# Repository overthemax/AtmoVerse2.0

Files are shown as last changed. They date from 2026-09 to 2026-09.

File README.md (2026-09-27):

<div align="center">

# AtmoVerse

**An e-ink weather station for your home: time, weather and a literary quote, on electronic paper.**

ESP32 · 5.83″ e-ink display · battery powered · self-updating from GitHub · Italian / English

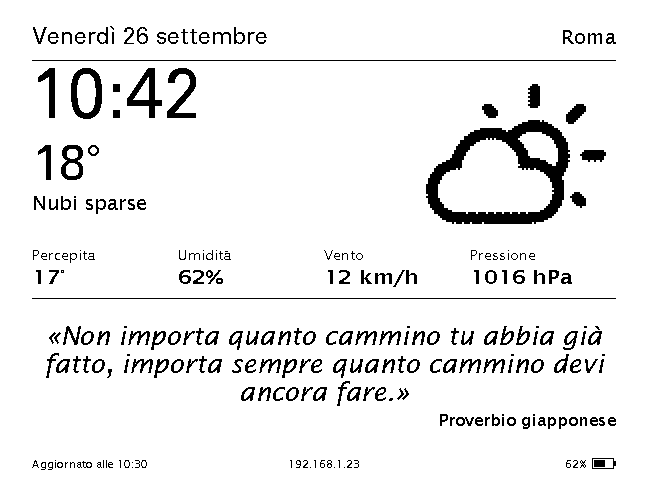
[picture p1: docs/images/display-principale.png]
AtmoVerse main screen


</div>

---

## What it does

- **Weather at a glance.** Temperature, feels-like, humidity, wind and pressure from OpenWeatherMap, with icons drawn for e-ink.
- **A literary clock.** At many minutes of the day it shows a quote from a book that mentions that exact time. Otherwise it picks a quote that suits the weather and the time of day, or one you scheduled for a given day and hour. The font adapts to the length, so quotes are never cut.
- **Setup from your phone.** On first start the display shows a QR code: scan it, the phone joins AtmoVerse's network and the setup page opens by itself.
- **Updates itself.** Firmware, web pages and icons come from GitHub releases, each file verified with SHA-256, with automatic rollback if a new firmware fails to start.
- **Lasts on battery.** On battery the WiFi is switched on only when needed and the board sleeps between minute refreshes. Touching a case screw wakes the web page for 10 minutes.
- **Two languages.** Display and web pages in Italian or English, chosen in the settings.
- **Keeps working offline.** A DS3231 real-time clock keeps the time without internet; if the home network drops, AtmoVerse reconnects by itself.

<table>
  <tr>
    <td align="center" width="50%">
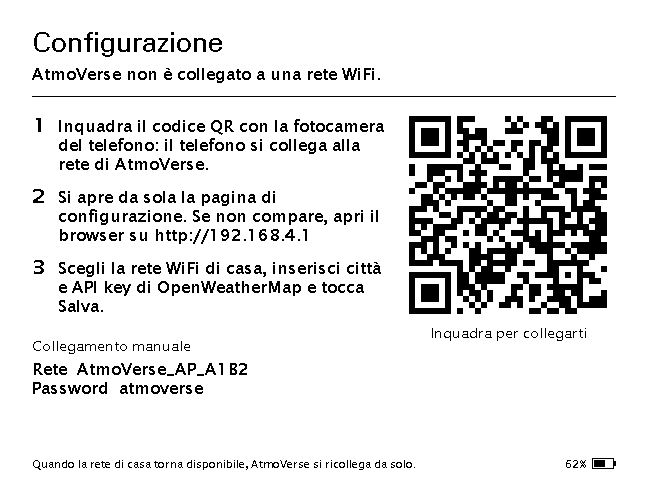
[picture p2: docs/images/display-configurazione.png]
Setup screen with QR code
      <br>
      <sub><b>First setup</b> · scan the QR code and follow three steps</sub>
    </td>
    <td align="center" width="50%">
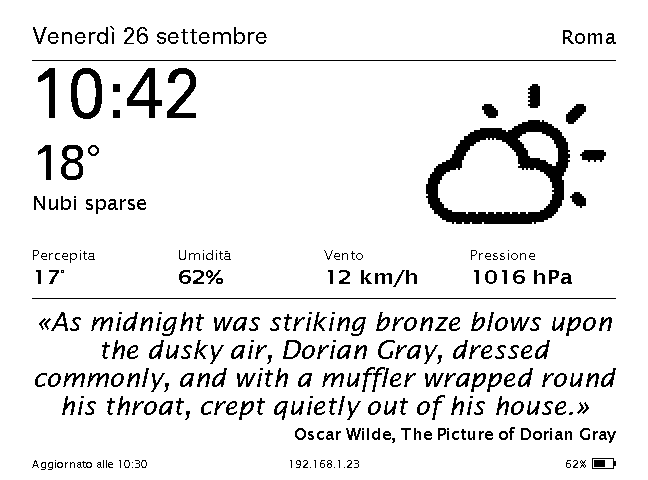
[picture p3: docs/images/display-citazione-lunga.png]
Long quote with adaptive font
      <br>
      <sub><b>Adaptive font</b> · long quotes stay whole</sub>
    </td>
  </tr>
  <tr>
    <td align="center" width="50%">
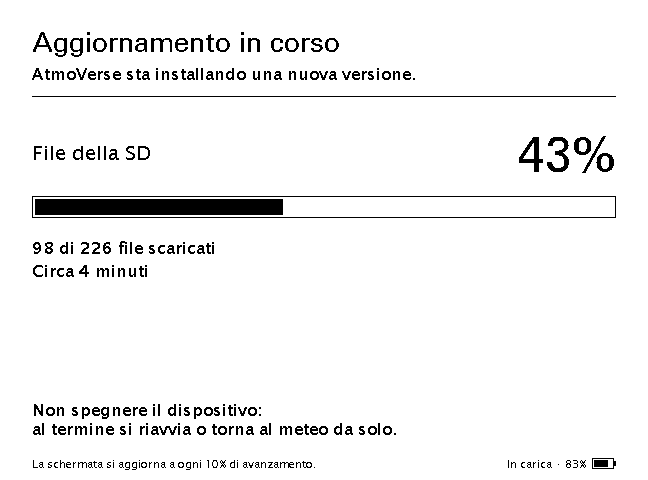
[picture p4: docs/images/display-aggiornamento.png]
Update in progress screen
      <br>
      <sub><b>Updates</b> · progress, files and remaining time</sub>
    </td>
    <td align="center" width="50%">
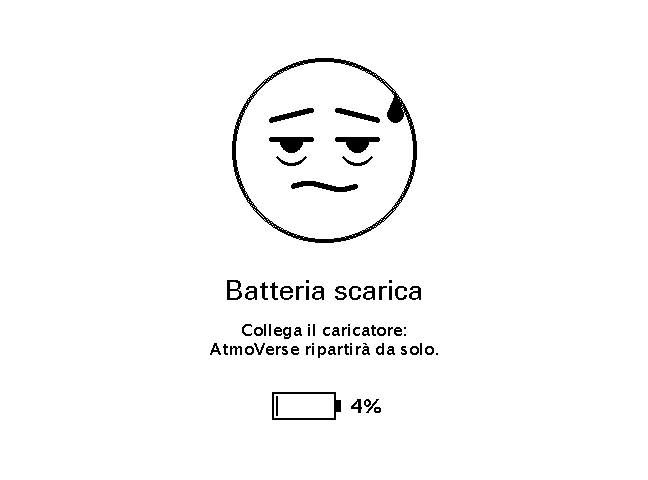
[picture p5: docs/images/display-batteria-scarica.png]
Empty battery screen
      <br>
      <sub><b>Battery empty</b> · the board sleeps until it is charged</sub>
    </td>
  </tr>
</table>

<sub>Images are rendered from the code with the display's real fonts (<code>tools/preview_display.py</code>), with sample data, in Italian.</sub>

---

## Hardware

| Part | Model | Connection |
|---|---|---|
| Board | WEMOS LOLIN32 (ESP32, 4 MB flash) | — |
| Display | 5.83″ e-ink 648×480, GDEW0583T8 (bare panel + driver board) | SPI (VSPI): BUSY 4 · RST 16 · DC 17 · CS 5 · SCK 18 · MOSI 23 |
| SD card | microSD FAT32 module | SPI (HSPI): CS 14 · SCK 27 · MOSI 26 · MISO 25 |
| Clock | DS3231 | I²C (Wire1): SDA 13 · SCL 15 |
| Battery | LiPo pack, 2 × 3500 mAh in parallel (66 × 43 × 13 mm) | measured by INA219 on I²C (Wire): SDA 32 · SCL 33, address 0x41 |
| Touch button | a case screw wired to GPIO2 (touch T2) | ring terminal under the screw |

### Case

A two-part desk case with soft rounded lines and a cylindrical stand that tilts the display by 15°. The front frame holds the panel; the back cover carries the stand and cradles for the battery and modules, and closes with four M3 screws into heat-set inserts.

<table>
  <tr>
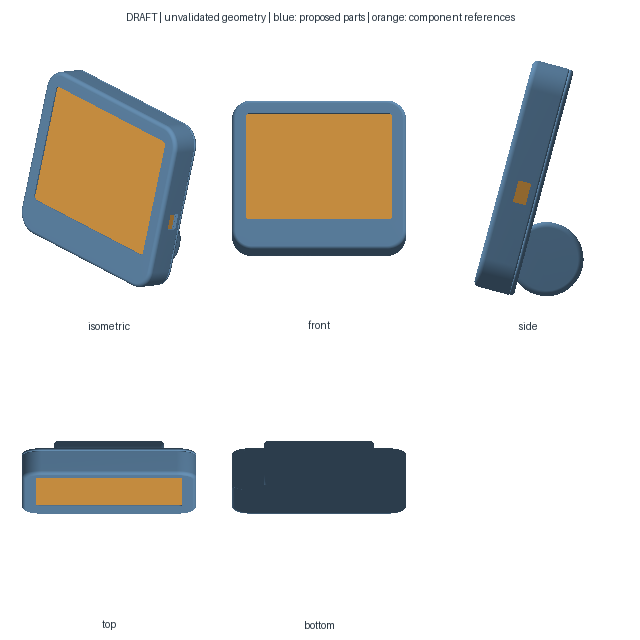
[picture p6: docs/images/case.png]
Case on the desk
    <td align="center" width="50%"><br><sub><b>On the desk</b></sub></td>
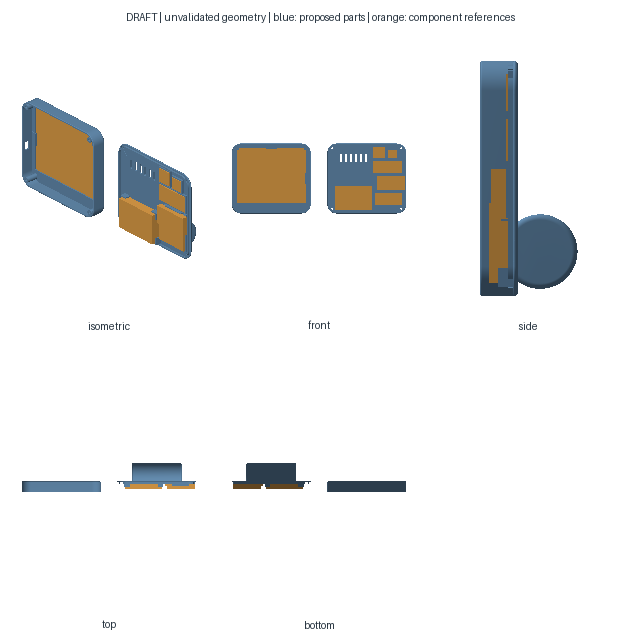
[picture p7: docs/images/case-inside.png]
Case exploded view
    <td align="center" width="50%"><br><sub><b>Inside</b> · frame and back cover</sub></td>
  </tr>
</table>

- Print-ready files: [`cad/stampa/`](cad/stampa) (STL and STEP). Print the frame face down; print the back cover standing on its bottom edge, with supports under the cylinder.
- Parametric source: [`cad/model_build.py`](cad/model_build.py) (build123d).
- Hardware: 4 × M3 screws, 4 × M3 heat-set inserts (Ø 4 mm), one M3 ring terminal for the touch screw.
- Module sizes are measured: LOLIN32 50.5 × 26.3 mm, e-paper driver 48.5 × 22.7 mm (its thickness, 6 mm, is estimated).

---

## Installation

### 1. First firmware upload (once)

One USB upload is enough: from then on AtmoVerse updates itself.

Requirements: [Arduino CLI](https://arduino.github.io/arduino-cli/) or Arduino IDE with **esp32 core 3.3.8** and these libraries:

| Library | Version |
|---|---|
| GxEPD2 | 1.6.9 |
| Adafruit GFX Library · Adafruit BusIO | 1.12.6 · 1.17.4 |
| U8g2_for_Adafruit_GFX | 1.8.0 |
| ArduinoJson | 7.4.3 |
| RTClib | 2.1.4 |
| Adafruit INA219 | 1.2.3 |

Connect the board and run, from PowerShell in the project folder:

```powershell
.\upload_lolin32_bigapp.ps1 -Port COM4
```

The script uses `partitions.csv`, which splits the flash into two 1.9 MB app slots needed by the automatic updates.

### 2. SD card

Any FAT32 microSD, even empty: web pages and icons are downloaded from GitHub the first time AtmoVerse goes online.

### 3. First setup

1. Switch AtmoVerse on: with no network configured it shows the QR code screen.
2. Scan the QR code with your phone camera. The phone joins `AtmoVerse_AP_xxxx` and the setup page opens (otherwise open `http://192.168.4.1`).
3. Enter your home WiFi, your city and an [OpenWeatherMap API key](https://openweathermap.org/api) (free), then tap **Save**.

AtmoVerse restarts, connects, downloads what is missing and shows the weather. The interface language can be changed later in **Settings → Language**.

---

## Quotes

For every display refresh the quote is chosen in this order:

1. **Scheduled**, if one is active: with a start time and duration, days of the week, or a date (every year or once).
2. **Literary clock**: a quote that mentions the current time, from `/clock/00.txt … 23.txt` on the SD card (optional).
3. **Weather**: a quote from the `quotes.json` section for the current weather (`rain`, `light_rain`, `thunderstorm`, `storm`, `clear_sky`, `few_clouds`, `scattered_clouds`, `cloudy`, `fog`, `snow`, `wind`), preferring quotes tagged for the time of day (`period`: `morning`, `afternoon`, `evening`, `day`, `night`) and the season (`season`: `winter`, `spring`, `summer`, `autumn`).

Everything is edited from the web editor (`/quotes-editor.html`), which has two tabs:

- **Weather and scheduled** — the quotes in `quotes.json`.
- **Literary clock** — one hour at a time, with the covered minutes for each hour and a warning on quotes too long for the display (checked by the board with the real fonts).

Example of a scheduled quote in `quotes.json`:

```json
"scheduled": [
  { "text": "Good morning! Every morning is a blank page.", "author": "Anonymous",
    "at": "07:00", "duration": 90, "days": "mon,tue,wed,thu,fri" }
]
```

`date` (`"12-25"` every year, `"2026-12-25"` once) can replace or accompany `at`. Files written before version 2.1.17 use Italian names (`programmate`, `ora`, `durata`, `giorni`, `data`, `pioggia`…): the device still reads them, and the editor converts the file to the English names on the first save, after downloading a backup copy. The `/orari` folder is renamed to `/clock` automatically at start-up.

The `/clock` files can also be generated from a CSV `HH:MM|phrase|text|work|author`. They live on the SD card only and are never part of the repository or of the updates:

```bash
python tools/make_clock_quotes.py quotes.csv E:/
```

---

## Power

| Power source | Behaviour |
|---|---|
| **Charger connected** | Everything always on: WiFi, web page, display refresh every minute. |
| **Battery** | WiFi off except for short windows: weather and time every 30 minutes, update check every 6 hours. Between minute refreshes the ESP32 is in light sleep. |
| **Battery, after a touch** | Touching the screw wakes the board: WiFi and web page stay on for 10 minutes, extended by every request. A WiFi icon next to the city shows when the WiFi is on. |

Plugging or unplugging the charger is detected within 2 seconds. The touch threshold is recalibrated at every change of power source, and false touches are ignored.

Battery levels: a warning in the footer at 15%, and at 5% the display shows an empty-battery screen and the board sleeps, checking every 30 minutes until it is charged. A new firmware is not installed below 25% unless the charger is connected.

---

## Automatic updates

At start-up and every 6 hours AtmoVerse checks the latest release and downloads only what changed.

- **Chain of trust.** The release information comes from `api.github.com` with a verified certificate, including the SHA-256 of `manifest.json`. The manifest is accepted only if its hash matches, and it carries the SHA-256 of the firmware and of every SD file. GitHub serves release files from a CDN whose Let's Encrypt "Root YR" chain the ESP32 certificate bundle cannot verify, so those downloads are encrypted but checked by hash instead.
- **SD files** (`sd_files/`): prepared in `/upd` and applied all together, even after an interruption. The release the SD card matches is remembered, so the periodic check skips re-hashing every file (a manual check from the web page always does the full check).
- **Firmware**: written to the second app slot, 3 attempts. If the new version does not survive its first 60 seconds, the bootloader goes back to the previous one and the faulty version is never downloaded again.
- **Personal files** (settings, `quotes.json`, `/clock`): never overwritten.
- If the SD card is full, the display explains how much space is needed.

### Publishing a new version

```bash
git tag v2.1.11
git push origin v2.1.11
```

The GitHub Action [`release.yml`](.github/workflows/release.yml) builds the firmware, generates the manifest with [`tools/make_manifest.py`](tools/make_manifest.py) and publishes the release. Devices install it at their next check, or immediately with **Settings → Check for updates**.

---

## Web interface

Reachable at the IP address shown at the bottom of the display (during setup: `http://192.168.4.1`). Designed for smartphones first. The pages are written in Italian and translated to English by [`sd_files/www/i18n.js`](sd_files/www/i18n.js) when English is selected.

<table>
  <tr>
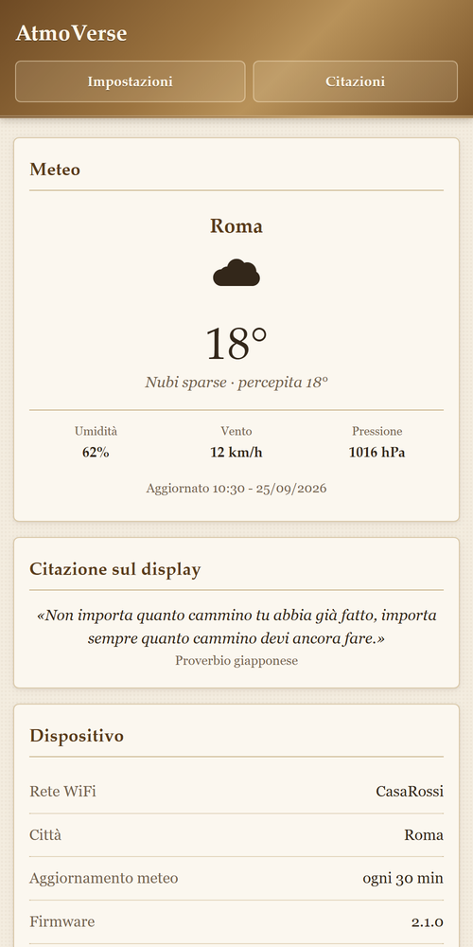
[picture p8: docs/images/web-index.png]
Home with weather and quote
    <td align="center" width="33%"><br><sub><b>Home</b></sub></td>
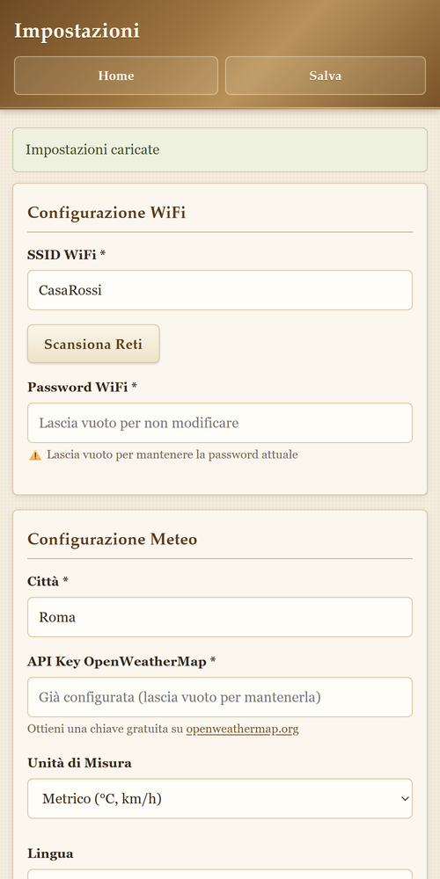
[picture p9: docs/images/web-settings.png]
Settings
    <td align="center" width="33%"><br><sub><b>Settings</b></sub></td>
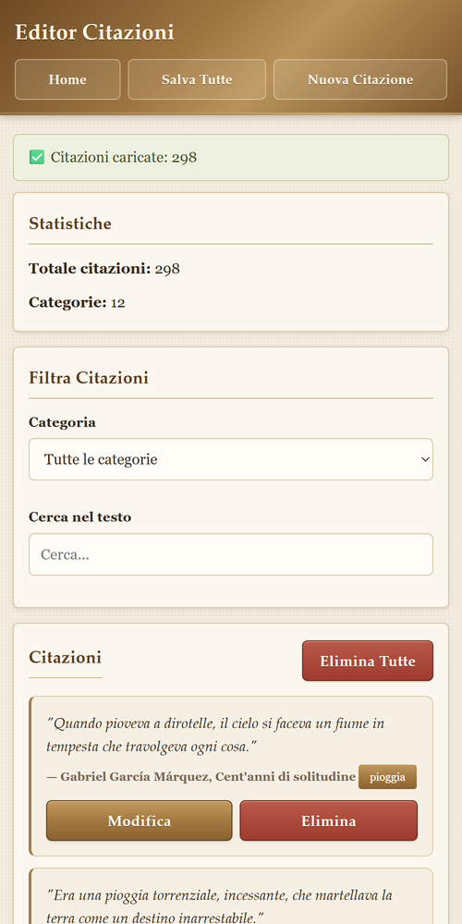
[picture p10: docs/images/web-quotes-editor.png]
Quote editor
    <td align="center" width="33%"><br><sub><b>Quotes</b></sub></td>
  </tr>
</table>

| API | Description |
|---|---|
| `GET /api/weather` | Current weather |
| `GET/POST /api/settings` | Read or save the settings. The API key is never returned; an empty password or API key keeps the stored one |
| `GET /api/wifi/scan` | Visible WiFi networks |
| `GET /quotes.json` · `POST /api/quotes/raw` | Read or save the weather and scheduled quotes (the whole file, written via a temporary file) |
| `GET /api/quote/current` | Quote shown on the display |
| `GET /api/clock` | Literary clock summary: quotes and covered minutes per hour |
| `GET /api/clock?h=8` · `?h=8&fit=1` | One hour of the literary clock, or which of its quotes fit the display |
| `POST /api/clock?h=8` | Save one hour (plain text, max 64 KB, written via a temporary file) |
| `GET /api/battery` | Voltage, current, percentage, charging |
| `GET /api/health` | Uptime, free memory, IP address, WiFi signal, SD card (used by the diagnostics page) |
| `POST /api/update/check` | Check for updates now |
| `POST /api/restart` | Restart the device |

> The web interface has no password: anyone on your home network can change the settings. Use AtmoVerse only on networks you trust.

---

## Architecture

The ESP32's two cores are used like this:

| Core | Runs |
|---|---|
| **Core 1** · main loop | Web server and captive portal, weather, updates, quotes, battery, RTC, SD card, power management |
| **Core 0** · display task | Drawing and refreshing the e-ink panel (about 4.5 s), at low priority next to the WiFi stack |

The loop prepares a snapshot of the screen (data, quote, icon already read from the SD card) and hands it to the display task, then goes straight back to the network: the web page keeps answering during a refresh. The display task never touches the SD card or the network; the only shared data is the pending screen, protected by a mutex. The display and the SD card use separate SPI buses, so they really work in parallel.

The CPU runs at 80 MHz, downloads included: raising it to 240 MHz during downloads made the HTTPS connections fail.

## Project layout

| File | Contents |
|---|---|
| `AtmoVerse_2.0.ino` | Start-up, main loop, network and periodic tasks |
| `DisplayTask.cpp` | Display task on core 0 |
| `Screens.cpp` | Display screens: layout, typography, adaptive quote, WiFi icon |
| `Display.cpp` | Building the screens in the loop (data, quote, icon) |
| `EcoPower.cpp` | Battery power saving, WiFi windows, light sleep, touch button |
| `Language.cpp` | Interface language |
| `Updater.cpp` | Automatic updates from GitHub with rollback |
| `WeatherUtils.cpp` | Weather from OpenWeatherMap (HTTPS) |
| `QuotesManager.cpp` | Quote selection |
| `QRCodeHelper.cpp` | QR codes with the ESP-IDF `esp_qrcode` component |
| `WebServer.cpp` · `WebMinimal.cpp` | Web interface, API and the minimal setup page built into the firmware |
| `NetworkUtils.cpp` | WiFi, access point mode, time zone |
| `BatteryManager.cpp` · `RTCManager.cpp` | Battery (INA219) and clock (DS3231) |
| `sd_files/` | SD card contents distributed with the updates |
| `cad/` | Case source and print files |
| `tools/` | Display previews, manifest, literary clock files, icon download and conversion |
| `tests/` | Hardware test sketches for the display and the SD card |

---

## Credits

- Weather icons: [Weather Icons](https://erikflowers.github.io/weather-icons/) by Erik Flowers ([SIL OFL 1.1](LICENSES/OFL-1.1.txt)), converted to bitmaps for e-ink.
- Fonts: FreeUniversal (SIL OFL 1.1) and Lucida Sans (© Bigelow & Holmes, X11 font license) through [U8g2](https://github.com/olikraus/u8g2).
- Weather data provided by [OpenWeather](https://openweathermap.org).
- Libraries: GxEPD2, Adafruit GFX, Adafruit BusIO, Adafruit INA219, RTClib, ArduinoJson, U8g2_for_Adafruit_GFX, Arduino core for ESP32 / ESP-IDF.
- Case modelled with [build123d](https://github.com/gumyr/build123d) and [Amagine3D](https://github.com/amagine-ai/Amagine3D).
- Design inspired by literary clocks such as [Author Clock](https://www.authorandco.com/).

Full list with versions and licenses: [THIRD_PARTY_NOTICES.md](THIRD_PARTY_NOTICES.md).

## License

The source code of AtmoVerse is released under the [MIT license](LICENSE) © overthemax.

The firmware binaries in the releases include GxEPD2, licensed under the GNU GPL v3, so each binary as a whole is distributed under the GPL v3; its complete source is this repository at the release tag. Third-party libraries, fonts and icons keep their own licenses, listed in [THIRD_PARTY_NOTICES.md](THIRD_PARTY_NOTICES.md).

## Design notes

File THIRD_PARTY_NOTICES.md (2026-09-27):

# Third-party notices

AtmoVerse's own source code is released under the [MIT license](LICENSE).
It uses the third-party software and assets listed below, each under its own license.

## Firmware binaries

The firmware published in the GitHub releases (`firmware.bin`) is built with the
libraries below. Because it links **GxEPD2**, which is licensed under the
**GNU GPL v3**, the firmware binary as a whole is distributed under the terms of
the GPL v3. The complete corresponding source code is this repository at the
release tag, plus the library versions listed here.

## Libraries (linked into the firmware, not included in this repository)

| Library | Version | License | Copyright |
|---|---|---|---|
| [GxEPD2](https://github.com/ZinggJM/GxEPD2) | 1.6.9 | GPL-3.0 | Jean-Marc Zingg |
| [Adafruit GFX Library](https://github.com/adafruit/Adafruit-GFX-Library) | 1.12.6 | BSD-2-Clause | Adafruit Industries |
| [Adafruit BusIO](https://github.com/adafruit/Adafruit_BusIO) | 1.17.4 | MIT | Adafruit Industries |
| [Adafruit INA219](https://github.com/adafruit/Adafruit_INA219) | 1.2.3 | BSD | Adafruit Industries |
| [RTClib](https://github.com/adafruit/RTClib) | 2.1.4 | MIT | Adafruit Industries, JeeLabs |
| [ArduinoJson](https://github.com/bblanchon/ArduinoJson) | 7.4.3 | MIT | Benoît Blanchon |
| [U8g2_for_Adafruit_GFX](https://github.com/olikraus/U8g2_for_Adafruit_GFX) | 1.8.0 | BSD-2-Clause | olikraus |
| [Arduino core for ESP32](https://github.com/espressif/arduino-esp32) | 3.3.8 | LGPL-2.1 | Espressif Systems |
| [ESP-IDF](https://github.com/espressif/esp-idf) (incl. mbedTLS, esp_http_client, esp_qrcode) | bundled with the core | Apache-2.0 (esp_qrcode uses Project Nayuki's QR Code generator, MIT) | Espressif Systems and contributors |

## Fonts (compiled into the firmware from U8g2)

| Font | Used for | License |
|---|---|---|
| FreeUniversal (`u8g2_font_fur*`) | time and temperature | SIL Open Font License 1.1 — FreeUniversal © Stephen Wilson 2009, based on Sil Sophia © SIL International 1994–2008 |
| Lucida Sans (`u8g2_font_lu*`) | text, labels, quotes | X11 bitmap fonts by Bigelow & Holmes: © Bigelow & Holmes 1985, 1986, redistributed under the X Window System font license. Lucida is a registered trademark of Bigelow & Holmes |

## Icons (included in this repository)

`sd_files/icons/` are converted from
[Weather Icons](https://erikflowers.github.io/weather-icons/) by Erik Flowers,
licensed under the [SIL Open Font License 1.1](LICENSES/OFL-1.1.txt).

## Data and services

- Weather data: [OpenWeather](https://openweathermap.org), used through the
  user's own API key and under OpenWeather's terms of service (data licensed
  CC BY-SA 4.0). Attribution: *Weather data provided by OpenWeather*.
- Updates: GitHub Releases and the GitHub REST API.

## Quotes

Quotes are short excerpts attributed to their authors and works. The literary
clock files (`/clock`) are not part of this repository or of the updates: they
stay on the user's own SD card.

## Tools (not distributed with the firmware)

- The case is modelled with [build123d](https://github.com/gumyr/build123d)
  (Apache-2.0) and the [Amagine3D](https://github.com/amagine-ai/Amagine3D)
  skill (Apache-2.0).
- The case design is original; its soft, rounded look was inspired by
  literary clocks such as [Author Clock](https://www.authorandco.com/). No
  part of their design files, logos or trademarks is used.

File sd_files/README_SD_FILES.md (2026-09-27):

# SD card files

The firmware keeps this folder in sync by itself: at every release the
automatic update downloads the files that changed (see `Updater.cpp` and
`tools/make_manifest.py`). You only need to copy it by hand on a card that
has never been online.

```
SD card
├── conf.json        Settings (created by the device, never overwritten by updates)
├── quotes.json      Weather and scheduled quotes (downloaded only if missing)
├── icons/           Weather icons, 1-bit BMP (Weather Icons by Erik Flowers)
├── www/             Web interface: index, settings, quotes editor, diagnostics
└── clock/           Optional: literary clock quotes, one file per hour
                     (made with tools/make_clock_quotes.py, never in git)
```

Files you add yourself are never deleted: an update only writes the files
listed in the release manifest.

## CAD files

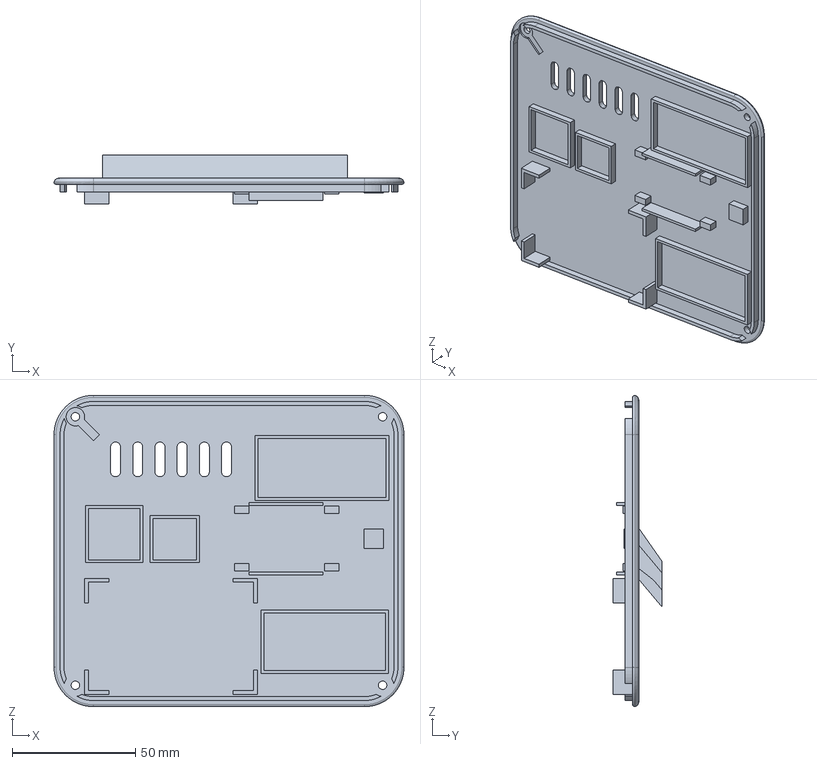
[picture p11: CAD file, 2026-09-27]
cad/stampa/atmoverse-coperchio.step
141.9 x 19.9 x 126.2 mm

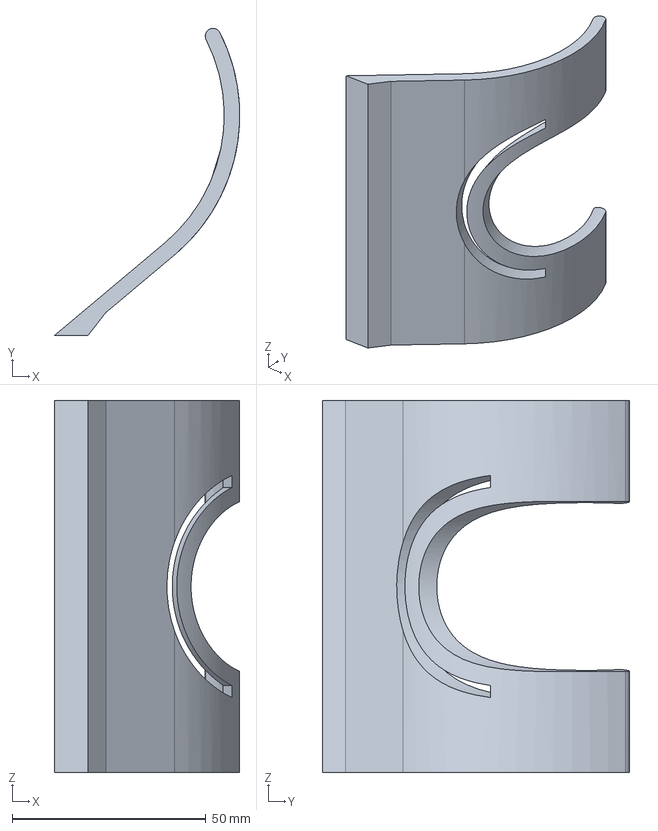
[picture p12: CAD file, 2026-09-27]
cad/stampa/atmoverse-supporto.step
47.8 x 79.3 x 96.0 mm

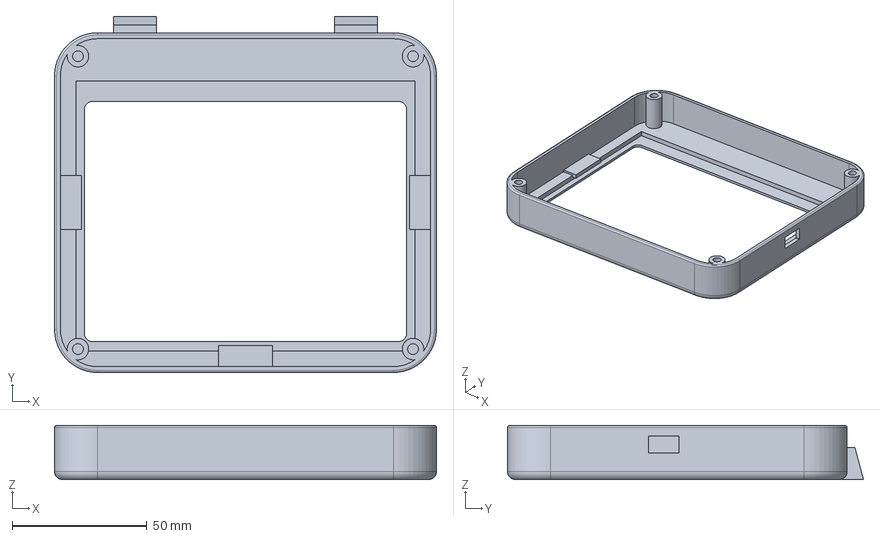
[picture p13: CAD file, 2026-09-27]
cad/stampa/atmoverse-cornice.step
142.0 x 132.4 x 20.1 mm

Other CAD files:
cad/stampa/atmoverse-coperchio.stl
cad/stampa/atmoverse-cornice.stl
cad/stampa/atmoverse-supporto.stl

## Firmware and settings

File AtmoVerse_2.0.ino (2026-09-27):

/*
 * AtmoVerse 2.0
 * Weather and quotes on an ESP32 with an e-ink display and a web interface
 */

// Core libraries
#include <Arduino.h>
#include <SPI.h>
#include <SD.h>
#include <WiFi.h>
#include <time.h>

// Project modules
#include "Hardware.h"
#include "Config.h"
#include "NetworkUtils.h"
#include "WeatherUtils.h"
#include "WebServer.h"
#include "Display.h"
#include "AtmoVerseConstants.h"
#include "QuotesManager.h"
#include "BatteryManager.h"
#include "RTCManager.h"
#include "Updater.h"
#include "Version.h"
#include "DisplayTask.h"
#include "EcoPower.h"

// The loop also runs the HTTPS connections (weather, updates): the
// default 8 KB stack is at its limit during the TLS handshake
SET_LOOP_TASK_STACK_SIZE(16 * 1024);

// Automatic updates from GitHub (see Updater.h)
const unsigned long UPDATE_CHECK_MS     = 6UL * 60 * 60 * 1000;  // Check every 6 hours
const unsigned long UPDATE_RETRY_MS     = 10UL * 60 * 1000;      // New attempt after an error
const unsigned long FIRMWARE_HEALTHY_MS = 60UL * 1000;           // After 60 s the firmware is confirmed
const unsigned long AP_RETRY_MS         = 5UL * 60 * 1000;       // In AP mode: new attempt on the configured network

// ---------------------------------------------------------------------------
// Battery empty: deep sleep
// ---------------------------------------------------------------------------
// At the critical level the display shows the tired face and the board
// sleeps, waking every 30 minutes only to measure the battery. The variable
// in RTC memory survives deep sleep.
const uint64_t BATTERY_SLEEP_US = 30ULL * 60 * 1000000;
RTC_DATA_ATTR bool sleepingForBattery = false;

void enterBatterySleep() {
  Serial.printf("[BATTERY] Battery at %d%%: deep sleep, next check in 30 minutes\n",
                battery.getPercentage());
  sleepingForBattery = true;
  WiFi.disconnect(true);
  WiFi.mode(WIFI_OFF);
  esp_sleep_enable_timer_wakeup(BATTERY_SLEEP_US);
  Serial.flush();
  esp_deep_sleep_start();
}

// Wake-up from the battery sleep: measure and, if it is still empty and not
// charging, sleep again without touching display and WiFi (the face stays)
void checkBatteryAfterSleep() {
  if (!sleepingForBattery || esp_sleep_get_wakeup_cause() != ESP_SLEEP_WAKEUP_TIMER) {
    sleepingForBattery = false;
    return;
  }
  battery.begin();
  if (battery.isAvailable() && !battery.charging() &&
      battery.getPercentage() < BATTERY_CRITICAL_EXIT_PERCENT) {
    enterBatterySleep();
  }
  Serial.println("[BATTERY] Battery recharged: normal start");
  sleepingForBattery = false;
}

// Update check requested from the web page (see WebServer.cpp)
volatile bool updateCheckRequested = false;
void requestUpdateCheck() {
  updateCheckRequested = true;
}

// Time of the last weather update
unsigned long lastWeatherUpdate = 0;

// Time of the last display update
unsigned long lastDisplayUpdate = 0;

// Weather connection attempts
int networkRetryCounter = 0;

// Result of the last weather update
bool lastWeatherUpdateSuccess = true;

// Setup
void setup() {
  // CPU at 80 MHz to save power (WiFi works down to 80 MHz)
  setCpuFrequencyMhz(80);

  // Serial for debugging
  Serial.begin(115200);
  delay(1000);

  // After a sleep for an empty battery: if it is still empty, back to sleep here
  checkBatteryAfterSleep();
  
  // Let the system settle before the SD card
  delay(500);
  
  // --- SD CARD on HSPI, BEFORE THE DISPLAY ---
  // The SD card is mounted first to avoid SPI conflicts
  bool sdAvailable = initSD();
  if (sdAvailable) migrateClockFolder();  // /orari -> /clock (2.1.17)
  
  // --- DISPLAY: start and boot screen AFTER the SD card ---
  delay(BOOT_DELAY_MS);

  SPI.begin(EPD_SCK, -1, EPD_MOSI, EPD_CS); // VSPI for the display
  initDisplay();          // Also starts the display task on core 0
  displayStartupScreen();

  delay(BOOT_SPLASH_DURATION_MS);
  
  // Is there a settings file? (only with an SD card)
  bool configFileExists = false;
  if (sdAvailable) {
    configFileExists = SD.exists("/conf.json") || SD.exists("conf.json");
  }

  // Load the settings
  loadConfig();
  
  // Is a network name set?
  bool hasSSID = strlen(config.ssid) > 0;

  
  // The file exists and was read, but the settings are not valid:
  // maybe a read error. Read it again up to 3 times.
  if (configFileExists && !hasSSID && sdAvailable) {
    // Read again up to CONFIG_READ_MAX_RETRIES times before giving up on the settings
    for (int i = 0; i < CONFIG_READ_MAX_RETRIES; i++) {
      delay(CONFIG_RETRY_DELAY_MS);
      
      // Reload the settings
      loadConfig();
      hasSSID = strlen(config.ssid) > 0;
      
      if (hasSSID) {
        break;
      }
    }
  }

  // Detects a firmware rollback and completes an interrupted
  // update of the SD files
  initUpdater();
  Serial.println("[SETUP] AtmoVerse " ATMOVERSE_VERSION);
  Serial.printf("[SETUP] Last restart: %s\n", resetReasonText());

  // Time zone at once: the RTC time (UTC) is shown correctly
  // even without internet
  applyTimezone();

  // Random generator seeded with ADC noise and the hardware RNG
  randomSeed(analogRead(0) ^ (esp_random() & 0xFFFF));

  // Hardware started before AP mode: during the setup too the display
  // needs the battery and the RTC time
  initHardware();

  // Battery: the INA219 is always looked for; without it the battery is not shown
  battery.begin();
  ecoBegin();  // Touch button for the web page on battery

  // DS3231 RTC: sets the internal clock at once if present
  rtcBegin();

  // Final check of the settings
  if (!checkConfigValidity()) {
    // Settings not valid: start the access point
    startAccessPoint(true);
    showAPModeInfo();
    return;
  }


  // --- Normal start ---
  // Network configured but unreachable: AP mode for the setup.
  // In AP mode the loop tries the network again every 5 minutes (if nobody is connected to the AP).
  if (!setupWiFi()) {
    startAccessPoint(true);
    showAPModeInfo();
  }
  // Wait for the NTP sync (max 5 s), then update the DS3231
  // (NTP server and time zone are set by connectToWiFi)
  if (!apMode && isWiFiConnected()) {
    struct tm ntpTime;
    if (getLocalTime(&ntpTime, 5000)) {
      syncToRTC();
    }
  }
  // Without NTP, the RTC time is used if present
  if (rtcAvailable() && !rtcLostPower()) {
    syncFromRTC();
  }
  setupServer();
  getWeatherData();
  updateDisplay();
}

// Are we in the power saving hours?
bool isPowerSavingMode() {
  if (!config.powerSavingEnabled) {
    return false; // Power saving hours disabled
  }

  // Current time
  struct tm timeinfo;
  if (!getLocalTime(&timeinfo, 0)) {
    return false; // Time not available: normal mode
  }
  
  int currentHour = timeinfo.tm_hour;
  
  // Start hour later than the end hour
  // (e.g. from 22:00 to 7:00 of the next day)
  if (config.powerSavingStartHour > config.powerSavingEndHour) {
    return (currentHour >= config.powerSavingStartHour || currentHour < config.powerSavingEndHour);
  } else {
    return (currentHour >= config.powerSavingStartHour && currentHour < config.powerSavingEndHour);
  }
}

// Weather update interval for the current mode
unsigned long getUpdateInterval() {
  // Low battery: weather updated less often
  if (isPowerSavingMode() || (battery.isAvailable() && battery.getLevel() != BATTERY_LEVEL_OK)) {
    return config.powerSavingUpdateInterval * 60 * 1000; // Minutes to milliseconds
  } else {
    return config.normalUpdateInterval * 60 * 1000; // Minutes to milliseconds
  }
}

// Display refresh interval in ms
unsigned long getDisplayRefreshIntervalMs() {
  if (isPowerSavingMode()) {
    return (unsigned long)config.displayRefreshIntervalSecPowerSaving * 1000UL;
  } else {
    return (unsigned long)config.displayRefreshIntervalSec * 1000UL;
  }
}

// Main loop
void loop() {
  unsigned long currentMillis = millis();
  battery.update();  // Also without a sensor: look for it again every minute
  if (battery.isAvailable()) {

    // Charger plugged in/out: display updated at once (not at the next minute)
    static unsigned long lastChargePoll = 0;
    if (currentMillis - lastChargePoll >= 2000) {
      lastChargePoll = currentMillis;
      if (battery.pollCharging()) {
        ecoPowerChanged();
        lastDisplayUpdate = 0;
      }
    }

    // Critical level steady for at least a minute (two readings): face and sleep
    static unsigned long criticalSince = 0;
    if (battery.getLevel() == BATTERY_LEVEL_CRITICAL) {
      if (criticalSince == 0) {
        criticalSince = currentMillis;
      } else if (currentMillis - criticalSince >= 60000UL) {
        showBatteryEmpty();
        waitDisplayIdle(15000);  // The screen must be on the panel before sleeping
        enterBatterySleep();
      }
    } else {
      criticalSince = 0;
    }
  }
  
  // NTP sync every 30 minutes to keep the DS3231 accurate
  static unsigned long lastNTPSync = 0;
  const unsigned long NTP_SYNC_INTERVAL_MS = 30UL * 60UL * 1000UL; // 30 minutes
  // The first DS3231 update happens as soon as the NTP time is available
  // (at boot it may arrive after the 5 s wait in setup), then every 30 minutes.
  // No waiting: SNTP already keeps the system time in sync in the background.
  static bool rtcSynced = false;
  if (!apMode && WiFi.status() == WL_CONNECTED && time(nullptr) > 1700000000 &&
      (!rtcSynced || (unsigned long)(currentMillis - lastNTPSync) >= NTP_SYNC_INTERVAL_MS)) {
    lastNTPSync = currentMillis;
    if (syncToRTC()) {
      rtcSynced = true;
      Serial.println("[RTC] RTC updated with the NTP time");
    }
  }
  
  // After 60 seconds without a crash the firmware is confirmed: if a freshly
  // installed version crashes earlier, the bootloader goes back to the previous one
  static bool firmwareConfirmed = false;
  if (!firmwareConfirmed && currentMillis >= FIRMWARE_HEALTHY_MS) {
    markFirmwareHealthy();
    firmwareConfirmed = true;
  }

  static bool updateDue = true;  // First update check as soon as possible
  static unsigned long lastUpdateCheck = 0;
  static unsigned long updateWaitMs = UPDATE_CHECK_MS;

  // In AP mode with a configured network: new attempt every 5 minutes, only if
  // no phone is connected to the AP (not to interrupt the setup)
  static unsigned long apSince = 0;
  if (apMode) {
    if (apSince == 0) apSince = currentMillis;
    if (strlen(config.ssid) > 0 && WiFi.softAPgetStationNum() == 0 &&
        currentMillis - apSince >= AP_RETRY_MS) {
      Serial.println("[WIFI] AP mode: trying the configured network again");
      if (connectToWiFi(config.ssid, config.password)) {
        setupServer();
        getWeatherData();
        updateDisplay();
        updateDue = true;
      } else {
        startAccessPoint(true);
      }
      apSince = millis();
    }
  } else {
    apSince = 0;
  }

  // Battery saving: WiFi is switched on only when needed (weather and time,
  // updates, web page after a touch) and switched off right after
  bool eco = ecoActive();
  if (eco) {
    bool weatherDue = (unsigned long)(currentMillis - lastWeatherUpdate) >= getUpdateInterval();
    bool updatesDue = updateDue || updateCheckRequested || currentMillis - lastUpdateCheck >= updateWaitMs;
    if (weatherDue || updatesDue || ecoWebWindowOpen()) ecoEnsureWiFi();
  } else if (!apMode && strlen(config.ssid) > 0 && WiFi.getMode() == WIFI_OFF) {
    // Charger plugged in again after power saving: WiFi always on again
    ecoEnsureWiFi();
  }

  // Updates from GitHub: at boot (so also right after the first setup),
  // then every 6 hours; after an error, new attempt in 10 minutes.
  // The HTTPS certificates need the right time (NTP or RTC).
  // If a new firmware is installed, checkForUpdates() restarts the device.
  if (!apMode && WiFi.status() == WL_CONNECTED && time(nullptr) > 1700000000 &&
      (updateDue || updateCheckRequested || currentMillis - lastUpdateCheck >= updateWaitMs)) {
    bool manualCheck = updateCheckRequested;  // From the web page: full check of the files
    updateDue = false;
    updateCheckRequested = false;
    lastUpdateCheck = currentMillis;
    updateWaitMs = checkForUpdates(manualCheck) ? UPDATE_CHECK_MS : UPDATE_RETRY_MS;
  }

  // Weather updates only outside AP mode
  if (!apMode) {
    // Update interval for the current power mode
    unsigned long updateInterval = getUpdateInterval();
    
    // Weather update at the computed interval
    if ((unsigned long)(currentMillis - lastWeatherUpdate) >= updateInterval) {
      lastWeatherUpdate = currentMillis;
      
      // Try to update the weather
      if (getWeatherData()) {
        // Success: reset the attempt counter
        networkRetryCounter = 0;
        lastWeatherUpdateSuccess = true;
        // The display is not updated here, only by the fixed-interval refresh
      } else {
        // Failure: count the attempts
        networkRetryCounter++;
        
        if (networkRetryCounter <= config.maxNetworkRetries) {
          // Try again in a minute
          lastWeatherUpdate = currentMillis - updateInterval + (60 * 1000);
        } else {
          // Maximum attempts reached
          lastWeatherUpdateSuccess = false;
          // The display is not updated here, only by the fixed-interval refresh
          // Reset the counter and try again at the next interval
          networkRetryCounter = 0;
        }
      }
    }
    
    // Display updated when the minute changes (not 60 s after boot, otherwise
    // the time shown could lag behind by almost a minute)
    static int lastShownMinute = -1;
    unsigned long refreshMs = getDisplayRefreshIntervalMs();
    bool refreshDue;
    struct tm nowTm;
    if (getLocalTime(&nowTm, 0)) {
      int minuteOfDay = nowTm.tm_hour * 60 + nowTm.tm_min;
      int stepMin = max(1, (int)(refreshMs / 60000UL));
      refreshDue = lastDisplayUpdate == 0 ||
                   (minuteOfDay != lastShownMinute &&
                    (minuteOfDay % stepMin == 0 ||
                     (unsigned long)(currentMillis - lastDisplayUpdate) >= refreshMs + 60000UL));
      if (refreshDue) lastShownMinute = minuteOfDay;
    } else {
      refreshDue = (unsigned long)(currentMillis - lastDisplayUpdate) >= refreshMs;
    }
    if (refreshDue) {
      lastDisplayUpdate = currentMillis ? currentMillis : 1;
      updateDisplay();
    }
  } else {
    // In AP mode the display shows the static setup screen.
    // The time is not updated: without NTP it is not reliable, and setPartialWindow crashed
  }
  
  
  // Web requests and captive portal DNS at every loop pass (about every 10 ms):
  // a page loads its HTML, CSS and scripts with separate requests, and serving
  // one every 800 ms made each page take about 3 seconds to open
  handleClientRequests();
  
  ecoPollTouch();

  // On battery with WiFi off: sleep until the next minute (not during the
  // touch test right after unplugging the charger, see EcoPower.cpp)
  if (eco) {
    ecoWiFiOffIfIdle();
    if (WiFi.getMode() == WIFI_OFF && !updateCheckRequested && !ecoTouchTestActive()) {
      ecoSleep(60000);
      return;
    }
  }

  // Short delay to keep the web server responsive
  // (the former 500 ms made the interface slow)
  delay(10); 
}

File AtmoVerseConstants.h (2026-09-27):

#ifndef ATMOVERSE_CONSTANTS_H
#define ATMOVERSE_CONSTANTS_H

// Access point SSID and password
#define ATMOVERSE_AP_SSID "AtmoVerse_AP"
#define ATMOVERSE_AP_PASSWORD "atmoverse"

// Default settings
#define ATMOVERSE_DEFAULT_CITY "Rome"
#define ATMOVERSE_DEFAULT_NTP "pool.ntp.org"
#define ATMOVERSE_DEFAULT_GMT_OFFSET 3600
#define ATMOVERSE_DEFAULT_DST_OFFSET 3600

// JSON buffer sizes
#define JSON_BUFFER_SMALL 512      // Small settings
#define JSON_BUFFER_MEDIUM 2048    // Full conf.json and weather data
#define JSON_BUFFER_LARGE 32768    // Large documents

// Timing and retries
#define CONFIG_READ_MAX_RETRIES 3
#define CONFIG_RETRY_DELAY_MS 500

// Display and boot (tuned for a fast start)
#define BOOT_SPLASH_DURATION_MS 500  // Ridotto da 800ms
#define BOOT_DELAY_MS 200           // Ridotto da 400ms

#endif // ATMOVERSE_CONSTANTS_H

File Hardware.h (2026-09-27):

#ifndef HARDWARE_H
#define HARDWARE_H

// E-ink display pins
#define EPD_BUSY    4    // GPIO04 - busy
#define EPD_RST     16   // GPIO16 - res (reset)
#define EPD_DC      17   // GPIO17 - d/c (data/command)
#define EPD_CS      5   // GPIO5 - cs (chip select)
#define EPD_SCK     18   // GPIO18 - sck (clock)
#define EPD_MOSI    23   // GPIO23 - sdi (data in/MOSI)

// SD card pins
#define SD_CS       14   // GPIO14 - cs (chip select SD)
#define SD_SCK      27   // GPIO27 - sck (clock SD)
#define SD_MOSI     26   // GPIO26 - mosi (data in SD)
#define SD_MISO     25   // GPIO25 - miso (data out SD)
// SD SPI clock: first attempt at 4 MHz (lower if needed)
#define SD_SPI_FREQ 4000000

#include <SPI.h>
extern SPIClass sdSPI;

// Definizioni hardware generali
#define SERIAL_BAUD_RATE 115200

// Altri parametri hardware
#define WEB_SERVER_PORT 80

// Hardware initialization
void initHardware();

// Safe, centralized SD card initialization
bool initSD();

// Why the board restarted last time (power on, crash, brownout...)
const char* resetReasonText();

// Global display object
// Black and white driver, as in the standard library
#include <GxEPD2_BW.h>
using DisplayType = GxEPD2_BW<GxEPD2_583_T8, GxEPD2_583_T8::HEIGHT>;
extern DisplayType display;

#endif // HARDWARE_H

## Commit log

2026-05-05 Fix: Risolti bug critici e migliorata stabilità sistema
    - SDFileManager.cpp: Ottimizzata lettura PROGMEM con reserve() e strlen_P una sola volta
    - WeatherUtils.cpp: Corretta formula fase lunare con algoritmo astronomico
    - WeatherUtils.cpp: Aggiunto WiFiClientSecure per connessioni HTTPS
    - WeatherUtils.cpp: Rimosso coordinate hardcoded e saveConfig() inutile
    - WebServer.cpp: Fix urldecode con gestione robusta caratteri esadecimali
    - BatteryManager.cpp: Migliorato test ADC con più letture e logica coerenza
    [BatteryManager.cpp, WeatherUtils.cpp, WebServer.cpp]
2026-05-05 Fix: Ridotto uso memoria nel caricamento citazioni
    [QuotesManager.cpp]
2026-05-05 Fix: Dashboard citazioni legge quotes.json
    [WebServer.cpp]
2026-05-05 Fix: fallback motivazione e accetta citazioni senza autore certo
    [QuotesManager.cpp]
2026-05-05 Fix: no fallback citazioni, mostra categoria OWM non trovata; fix mapping 501->pioggia
    [QuotesManager.cpp]
2026-05-05 Fix: selezione citazioni a pool cumulativo; randomSeed con esp_random()
    [AtmoVerse_2.0.ino, QuotesManager.cpp]
2026-05-05 Fix weather sync: switch HTTPS to HTTP, add client.stop(), enable logging
    [AtmoVerse_2.0.ino, WeatherUtils.cpp]
2026-09-25 Escludi CloudSecrets.h da git e aggiungi il modello CloudSecrets.example.h
    Il file con le credenziali di Arduino IoT Cloud è stato rimosso dalla storia
    locale (mai pubblicata) prima di pubblicare il repository.
2026-09-25 Lavoro in corso di maggio 2026: batteria INA219, RTC DS3231, font Kaufmann
    Modifiche che erano solo sul disco, salvate come punto di partenza.
    RTCManager.cpp include già la correzione di questa sessione: DS3231 su
    Wire1 (SDA 13, SCL 15, come da cablaggio) e ora salvata in UTC.
2026-09-25 Aggiornamento automatico da GitHub, logica AP, correzioni, batteria, citazioni programmate
    Rimosso
    - Arduino IoT Cloud (non usato) e ArduinoOTA senza password.
    Aggiornamento automatico (Updater.cpp, Version.h, partitions.csv)
    - Firmware e file della SD (pagine, 219 icone BMP, font) dalla release GitHub,
    verificati con SHA-256, applicati insieme; rollback automatico se il nuovo
    firmware non supera 60 s. quotes.json e layout.json non vengono sovrascritti.
    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
    [partitions.csv]
2026-09-25 Citazioni "orologio letterario" lette da /orari sulla SD
    - QuotesManager: se per il minuto attuale c'è una citazione in /orari/HH.txt
    la mostra (dopo le programmate, prima di quelle del meteo). Legge solo il
    file dell'ora corrente riga per riga; scarta le citazioni oltre 240 caratteri.
    - tools/prepara_citazioni_orarie.py: converte il CSV "HH:MM|frase|testo|opera|autore"
    nei 24 file da copiare sulla SD.
    - Le citazioni restano private: /orari e il CSV sono esclusi da git.
2026-09-26 Nuovo display, task del display sul core 0, correzioni di stabilità e sicurezza
    Display
    - Nuove schermate (Screens.cpp): font U8g2 con lettere accentate, griglia
    comune, icona BMP x2, citazione con carattere adattivo, QR in modalità AP.
    - Le citazioni a orario sono accettate se entrano davvero nel riquadro
    (quoteFitsDisplay) invece che sotto un limite fisso di 240 caratteri.
    Core
    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
2026-09-26 Interfaccia web: stile classico in bronzo e ottimizzazione per smartphone
    - style.css riscritto: pergamena e bronzo, titoli con grazie (Palatino/
    Georgia), testata e pulsanti con gradiente bronzo, struttura mobile first
    (campi a 16 px, pulsanti da 44 px, testata e azioni che vanno a capo).
    css/style.css importa lo stesso tema: un unico stile per tutte le pagine.
    - Home riscritta: meteo, citazione mostrata sul display e stato del dispositivo;
    vento convertito da m/s a km/h, testo escapato.
    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
2026-09-26 Release: installa anche U8g2_for_Adafruit_GFX (font del display)
    La compilazione della release v2.1.0 su GitHub falliva per la libreria mancante.
2026-09-26 RTC: aggiornato appena l'ora NTP è disponibile, non dopo 30 minuti
    All'avvio l'attesa di 5 s per NTP può non bastare: il DS3231 restava senza
    ora valida per mezz'ora. Ora viene impostato al primo giro del loop con l'ora
    sincronizzata, poi ogni 30 minuti, senza attese bloccanti.
2026-09-26 Aggiornamenti: manifest letto dalla SD una voce alla volta
    Il manifest (35 KB, ~250 file) veniva caricato tutto in RAM e convertito in
    un unico documento JSON: con WiFi e TLS attivi mancava un blocco di memoria
    abbastanza grande e il controllo falliva con "Manifest non valido".
    Ora il manifest si scarica sulla SD, l'intestazione si legge con un filtro e
    l'elenco dei file una voce alla volta; anche l'elenco dei file da scaricare
    sta sulla SD. Senza SD il manifest resta in RAM ma si leggono solo i dati del
    firmware. In caso di errore il log riporta il motivo e la memoria libera.
    [Updater.cpp]
2026-09-26 Aggiornamenti: download dei file della SD funzionante
    - raw.githubusercontent.com usa la catena Let's Encrypt "Root YR" -> ISRG
    Root X1: sull'ESP32 la verifica RSA-4096 della radice fallisce
    (esp-x509-crt-bundle 0x4290). I file della SD si scaricano con una
    connessione cifrata senza verifica del certificato; l'integrità resta
    garantita dallo SHA-256 di ogni file, preso dal manifest scaricato da
    github.com con certificato verificato.
    - Una sola connessione riutilizzata per tutti i file e tre tentativi per file.
    - Log con codice d'errore e memoria libera in caso di connessione fallita.
    - Versione 2.1.4.
    Provato sulla scheda: 226 file sincronizzati in circa 7-8 minuti.
    Co-Authored-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
    [Updater.cpp]
2026-09-26 Avanzamento aggiornamenti, spazio SD, avvisi batteria, solo INA219
    Aggiornamenti
    - Schermata di avanzamento: fase, percentuale, barra, file scaricati e tempo
    stimato; aggiornata a ogni 10% e non più di una volta ogni 20 s.
    - Controllo dello spazio libero sulla SD prima di scaricare (cluster FAT
    compresi); SD piena o scrittura fallita: schermata di errore e avviso
    persistente nel piè di pagina finché il problema non si risolve.
    - Firmware non installato con batteria sotto il 25% e non in carica.
    Batteria
    - Livelli con isteresi: al 15% avviso nel piè di pagina e meteo meno frequente;
    al 5% schermata "Batteria scarica" con faccina stanca e sonno profondo,
    risveglio ogni 30 minuti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
    [AtmoVerse_2.0.ino, BatteryManager.cpp, BatteryManager.h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]
2026-09-26 2.1.6: più spazio alle citazioni, orologio letterario nell'editor, aggiornamenti più rapidi
    - Display: dati meteo più in alto (riquadro citazione da 106 a 144 px),
    icona centrata sul disegno reale, autore allineato a destra che va a capo
    - Ora aggiornata allo scatto del minuto (prima poteva restare indietro fino a un minuto)
    - Editor: scheda "Orologio letterario" per leggere e salvare /orari un'ora alla volta,
    con copertura dei minuti e segnalazione delle citazioni troppo lunghe
    - Web server: GET/POST /api/orari (riepilogo, file dell'ora, verifica "entra nel display")
    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
2026-09-26 2.1.8: risparmio energetico a batteria, tasto a sfioramento, firmware da CDN GitHub, QR vero
    - A batteria il WiFi si accende solo per meteo/ora (30 min) e aggiornamenti
    (6 h); tra un minuto e l'altro light sleep. Col caricatore tutto resta acceso
    - Tocco sulla vite (GPIO2, touch T2): WiFi e pagina web per 10 minuti,
    prolungati a ogni richiesta; soglia ricalibrata a ogni cambio di
    alimentazione, falsi tocchi verificati e ignorati
    - Caricatore collegato/staccato rilevato in 2 s: display aggiornato subito,
    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
2026-09-26 2.1.11: Italian / English interface, update button, English README, case files
    - Language setting drives the interface: "it" keeps Italian, any other
    language switches display and web pages to English (weather descriptions
    still come from OpenWeatherMap in the chosen language)
    - Firmware: TR(it, en) for every display text (date, labels, footer, setup,
    update and battery screens, update errors)
    - Web: sd_files/www/i18n.js translates the pages, content added later,
    confirm/alert dialogs and the update status coming from the firmware
    - Settings: "Check for updates" button (POST /api/update/check)
    - README rewritten in English with the current features: literary clock
    editor, power sav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
    [atmoverse-coperchio.step, atmoverse-coperchio.stl, atmoverse-cornice.step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]
2026-09-26 Licensing clean-up: third-party notices, OFL text, removed proprietary assets
    - Removed KAUFMANN14/20pt7b.h (bitmaps of the proprietary Kaufmann typeface,
    no longer used)
    - Removed sd_files/fonts (digits rendered from Windows system fonts, unused)
    and dropped "fonts" from the managed SD files
    - Removed test-e.i_nk (vendor e-paper demo code without a license) and
    data/boards.txt, compile logs
    - THIRD_PARTY_NOTICES.md: libraries, versions and licenses; GxEPD2 is GPL-3.0,
    so release firmware binaries are distributed under the GPL v3
    - LICENSES/OFL-1.1.txt for the Weather Icons
    - README: full credits and license section
    - Web home: "Weather data provided by OpenWeather" attribution
    Co-A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
2026-09-26 2.1.13: battery sensor no longer dropped when the pack is full
    At start-up the INA219 was rejected when voltage was steady and current was
    zero, a check meant for a disconnected sensor. A fully charged pack with the
    charger stopped looks exactly like that, so after the 2.1.12 update the
    battery showed as unavailable. The check is removed (a missing INA219 already
    fails at begin()), and if the sensor is not found the firmware retries every
    minute instead of giving up until the next restart.
    [AtmoVerse_2.0.ino, BatteryManager.cpp]
2026-09-26 2.1.14: no crash when the WiFi is off, charger detected with a full battery
    - Web server: not polled while the power saving has switched the WiFi off;
    server.available() on a torn-down network stack crashed core 1
    (InstrFetchProhibited in lwIP pbuf handling); the server is also closed
    before switching the WiFi off
    - Battery: a discharge current below 8 mA means the charger is connected,
    also when the pack is full and no longer takes current. Before, a full
    battery on USB looked like "on battery", enabling power saving, switching
    the WiFi off and making the web page unreachable
    [BatteryManager.cpp, BatteryManager.h, EcoPower.cpp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]
2026-09-26 Case: measured LOLIN32 (50.5 x 26.3) and e-paper driver (48.5 x 22.7) sizes; module column anchored to the right wall
    [atmoverse-coperchio.step, atmoverse-coperchio.stl, atmoverse-cornice.step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]
2026-09-26 Case: battery at the bottom for a lower centre of gravity, 2.4 mm panel recess in a 3.6 mm front wall
    [atmoverse-coperchio.step, atmoverse-coperchio.stl, atmoverse-cornice.step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]
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2026-09-27 2.1.16: weather data 8 px higher (quote box 152 px), SD check skipped when the file list is unchanged
    - Header rule at y 54; labels/values at 252/276, rule at 290; quote box 300-452.
    Icon space 56-239 still fits the tallest icons (182 px).
    - Manifest: files_digest over the SD file list. The device stores it after a
    sync and skips the SD check when it has not changed (firmware-only releases).
    - When the list changed, files with a different size are queued without hashing.
    [Updater.cpp]
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2026-09-27 Fix review issues and add 12/24-hour clock option
    - Config: accept open WiFi networks, keep defaults on read failure,
    clamp values to valid ranges, save atomically via a temp file
    - Quotes: wind/storm categories now reachable, thresholds in m/s
    (imperial wind converted), drizzle and light rain mapped separately
    - Night detection from OpenWeather sunrise/sunset instead of fixed 19-7
    - Weather icons: direct mapping for every condition, no "sunny" fallback
    - Battery, RTC and power manager initialized before AP mode
    - Web server polled on every loop pass; new POST /api/restart
    - Update status messages localized; postponed firmware message kept
    - Diagnostics page rewritten in the index style;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
    [AtmoVerseConstants.h, AtmoVerse_2.0.ino, Config.cpp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]
2026-09-27 Use English names for the literary clock folder and quotes.json
    - Literary clock folder /orari -> /clock, renamed once at boot;
    API /api/orari -> /api/clock
    - quotes.json sections (rain, clear_sky, scheduled...), scheduled fields
    (at, duration, days, date), "time" -> "period", English tag values.
    The firmware still reads the pre-2.1.17 Italian names; the editor
    converts an old file on its first save, after downloading a backup
    - Editor served straight from the SD card (the text patch it applied no
    longer matched anything); scripts and styles are no longer cached for
    a day, so they update together with the pages
    - i18n: text split over several lines in the HTML is now translated
    -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
    [AtmoVerse_2.0.ino, QuotesManager.cpp, WebServer.cpp]
2026-09-27 Translate comments, serial logs and tools to English
    - Comments in firmware, web pages, styles, tools, workflow and test
    sketches translated (checked: code without comments unchanged)
    - Serial log messages in English; text shown to the user stays
    bilingual (TR() on the display, i18n.js on the web pages)
    - Commented-out debug code removed from Hardware.cpp, NetworkUtils.cpp
    and WeatherUtils.cpp; SD mount now reports a failure once
    - WeatherUtils: missing icon/description no longer passed as NULL to
    strlcpy; JsonDocument instead of the deprecated DynamicJsonDocument
    - Unused layout editor styles removed from style.css
    [partitions.csv]
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2026-09-27 Case: USB-C adapter flush with the wall, curved arc stand
    - LOLIN32 with a micro-USB to USB-C adapter (72.8 mm in total, adapter
    23.3 x 11 x 6 mm measured): the adapter passes through the right wall,
    flush with the outside, in an 11.4 x 6.4 mm opening (0.2 mm clearance)
    - The rear cylinder is replaced by a separate curved "arc" stand with a
    rising-sun cut-out, sliding into a dovetail on the back cover and
    resting on the desk like a rocking-chair runner (radius 45 mm); two
    wedge feet under the front edge. Forward tipping margin ~32 degrees
    (was ~7 with the cylinder)
    - New print file atmoverse-supporto (printed on its side, brim)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
    [atmoverse-coperchio.step, atmoverse-coperchio.stl, atmoverse-cornice.step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]
2026-09-27 Fix touch wake-up on battery: set the touch channel threshold
    With core 3.x the ESP32 touch driver ignores the threshold passed to
    touchSleepWakeUpEnable and keeps its default, 1.5% below the reading at
    boot. On battery the idle value is lower than that (boot is usually on
    USB): the board woke up continuously, every wake-up counted as a false
    touch and after three the touch wake-up was switched off. The channel
    threshold is now set with touchAttachInterrupt at every calibration.
    [EcoPower.cpp]
2026-09-27 Show why the board last restarted
    The restart reason (power on, crash, watchdog, brownout...) is printed at
    boot and shown on the diagnostics page and in /api/health, to explain
    unexpected restarts on battery.
    [AtmoVerse_2.0.ino, Hardware.cpp, Hardware.h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]
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2026-10-11 Touch screw: instant redraw, faster WiFi, long press to restart/reset
    - A touch or plugging in the charger redraws the display at once, before
    the WiFi connects; the footer shows the last known address and is
    redrawn only if it changes
    - Faster reconnect: the channel and access point of the last connection
    are reused (fallback to a full scan after 4 s), no fixed 1 s wait
    - On battery the web page stays reachable for 10 minutes after power-on
    - Long press on the touch screw: 10 s restart, 30 s erase the settings,
    45 s cancel. Nothing happens until the finger is lifted; a reading
    stuck for 60 s is treated as a fault
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2026-10-11 Case v2 cover: USB connector off-centre on the LOLIN32
    The micro-USB (and the straight USB-C adapter) sits along the lower long
    edge of the board, not in the middle. The opening in the printed frame
    is kept: the LOLIN32 supports on the cover move up 7.65 mm so the real
    adapter lands in it (0.2 mm clearance all round); the SD module moves
    with the board and 7 mm towards the centre to clear the top-right boss.
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
